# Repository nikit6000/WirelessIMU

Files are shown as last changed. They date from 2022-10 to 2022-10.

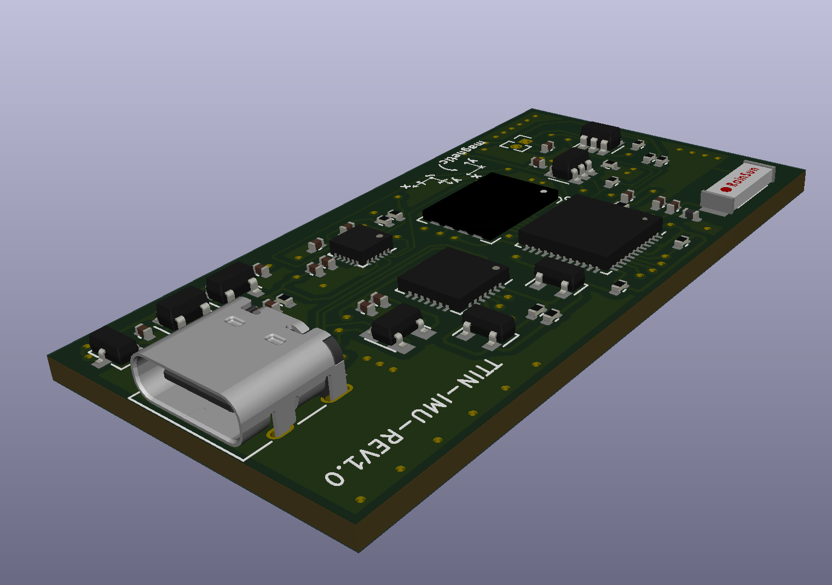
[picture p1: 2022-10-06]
Images/pcb.png

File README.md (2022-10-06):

# WirelessIMU
A board for wireless motion tracking based on `ESP32-PICO-D4` and `MPU9250`. You also can use `ICM-20948` instead of `MPU9250` but you needs to change LDO at `U1` place to 1.8V one

# Capabilities
* Capture RAW Gyroscope, Accelerometer data to embedded storage
* Control over BLE
* Captured data downloading via Wi-Fi

# Applications
* [iOS Application](https://github.com/tokareva13/WirelessIMU-Control)

# Authors
* [Nikita Tarkhov](https://github.com/nikit6000)
* [Tokareva Irina](https://github.com/tokareva13)

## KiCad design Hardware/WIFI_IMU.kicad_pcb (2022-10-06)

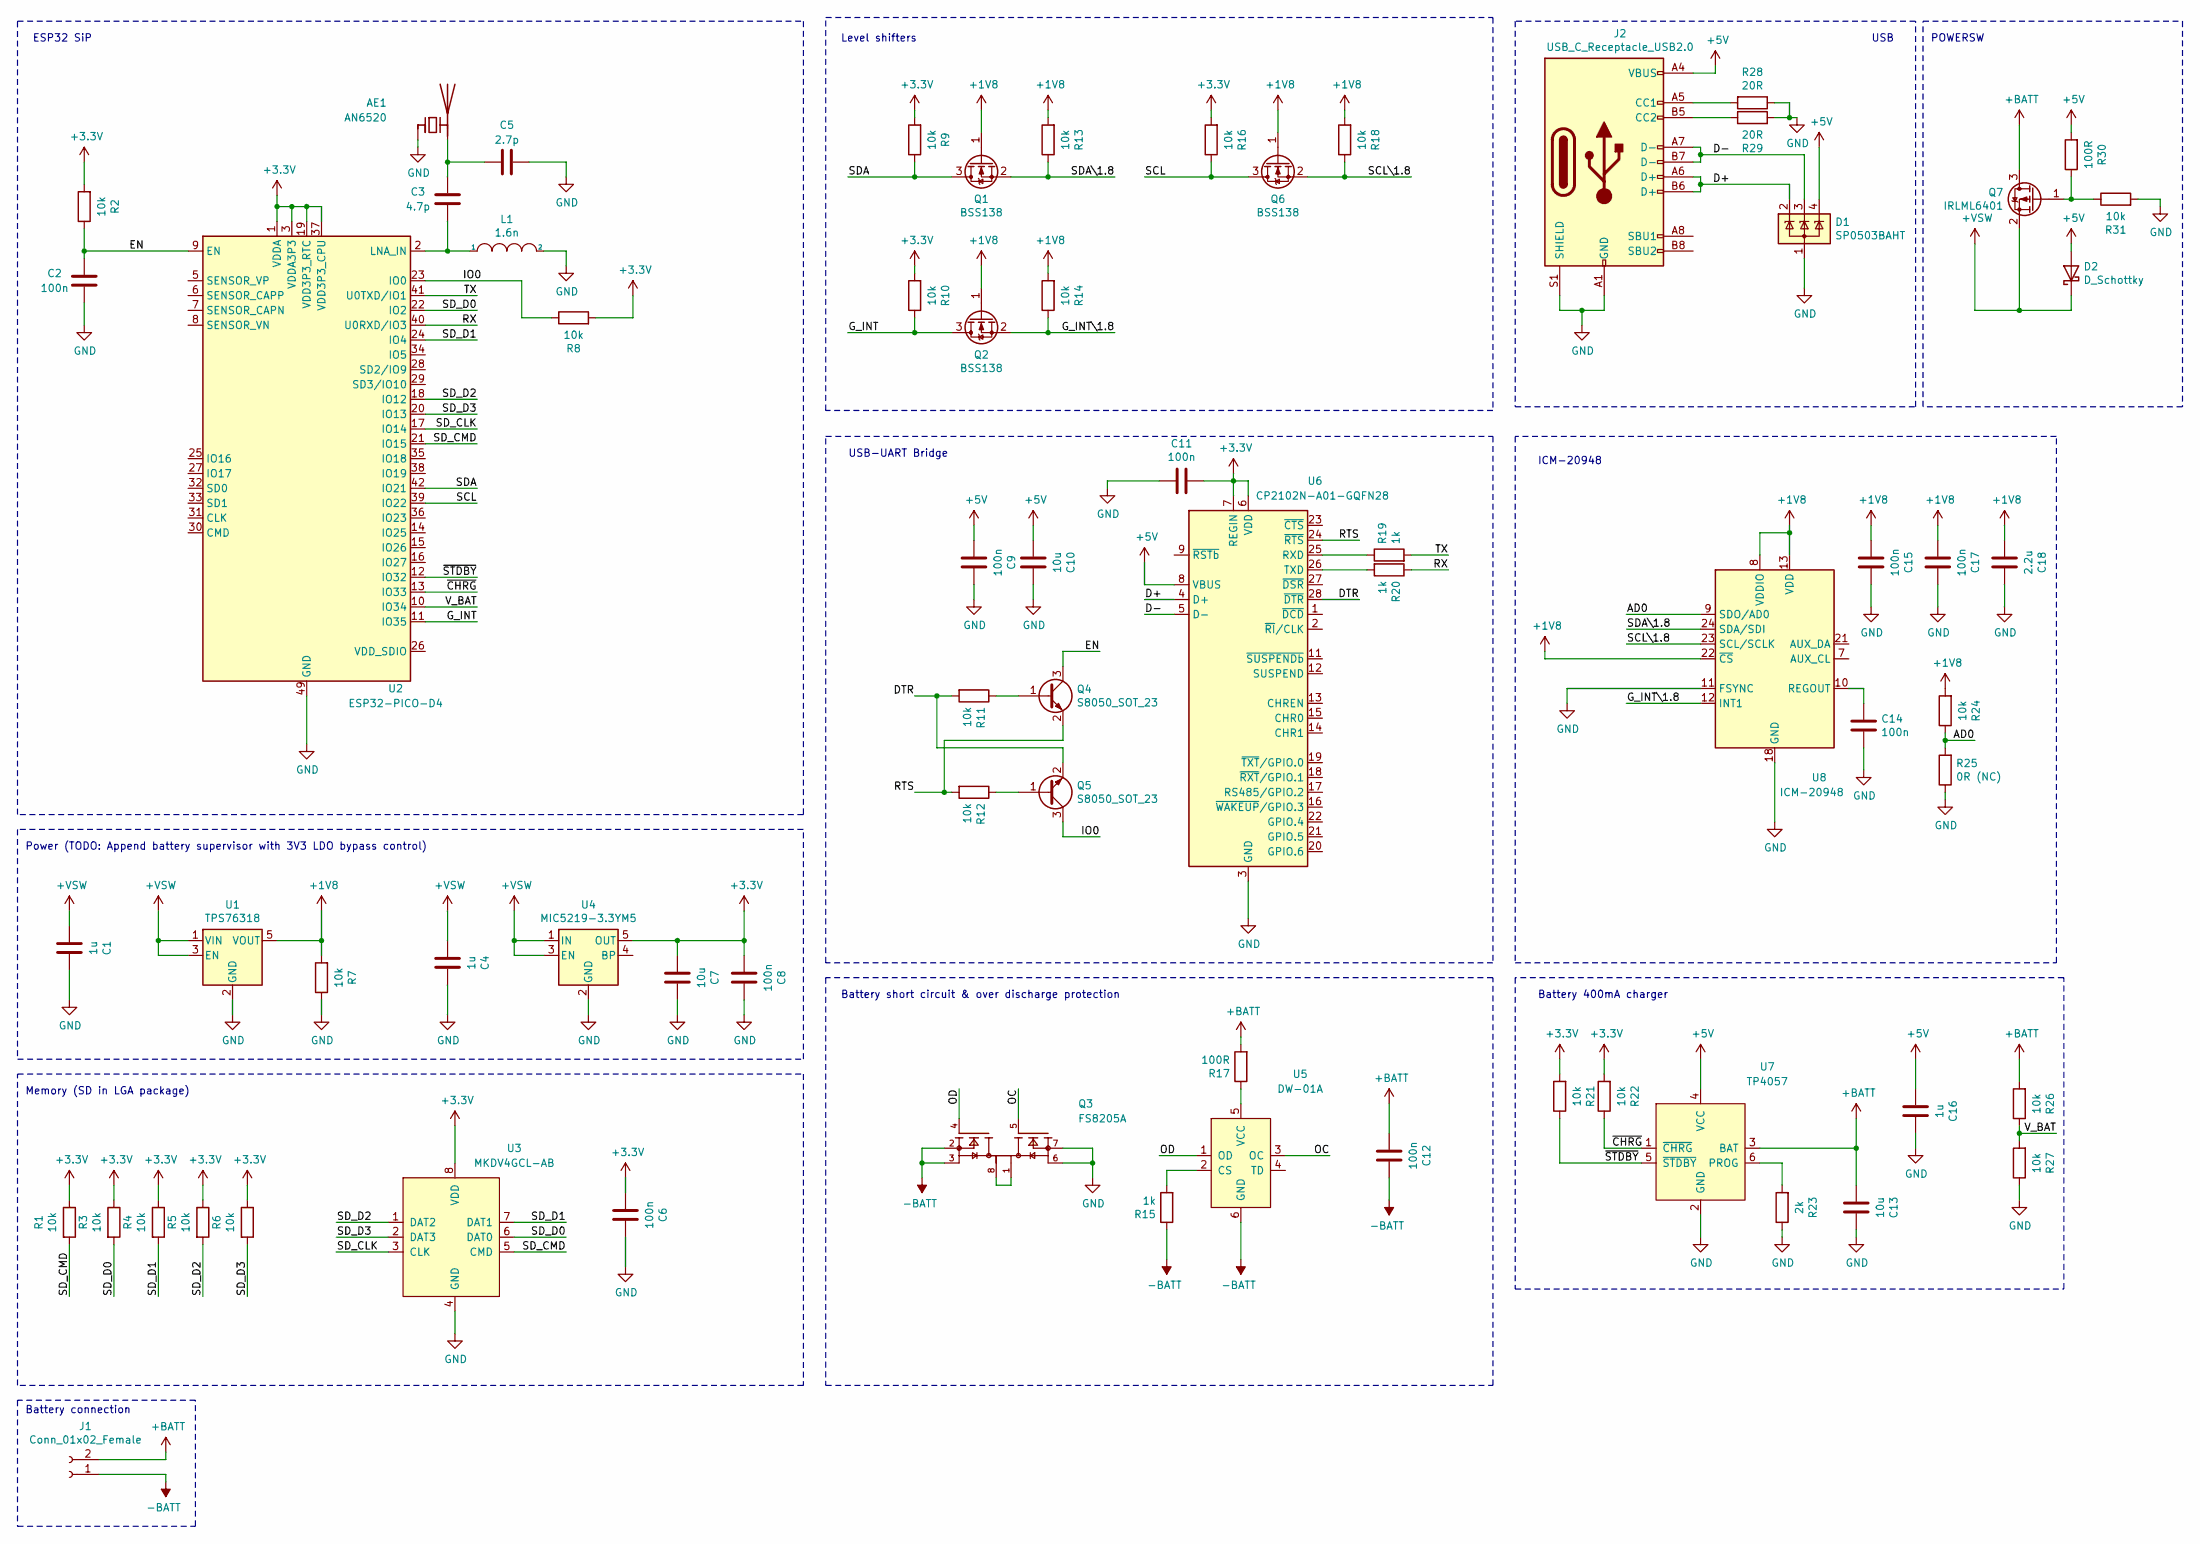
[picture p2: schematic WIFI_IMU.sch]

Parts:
AE1: AN6520; CHIP_ANTENNA_AN6520
C1, C4, C16: 1u; C_0402_1005Metric
C2, C6, C8, C9, C11, C12, C14, C15, C17: 100n; C_0402_1005Metric
C3: 4.7p; C_0402_1005Metric
C5: 2.7p; C_0402_1005Metric
C7, C10, C13: 10u; C_0402_1005Metric
C18: 2.2u; C_0402_1005Metric
D1: SP0503BAHT; SOT-143
D2: D_Schottky; D_SOD-323
J1: Conn_01x02_Female; PinHeader_1x02_P1.27mm_Vertical
J2: USB_C_Receptacle_USB2.0; USB_C_Receptacle_HRO_TYPE-C-31-M-12
L1: 1.6n; L_0402_1005Metric
Q1, Q2, Q6: BSS138; SOT-23
Q3: FS8205A; SOP65P640X120-8N; PARTREV 1.7
Q4, Q5: S8050_SOT_23; SOT-23
Q7: IRLML6401; SOT-23
R1, R2, R3, R4, R5, R6, R7, R8, R9, R10, R11, R12, R13, R14, R16, R18, R21, R22, R24, R26, R27, R31: 10k; R_0402_1005Metric
R15, R19, R20: 1k; R_0402_1005Metric
R17, R30: 100R; R_0402_1005Metric
R23: 2k; R_0402_1005Metric
R25: 0R (NC); R_0402_1005Metric
R28, R29: 20R; R_0402_1005Metric
U1: TPS76318; SOT-23-5
U2: ESP32-PICO-D4; QFN-48-1EP_7x7mm_P0.5mm_EP5.3x5.3mm
U3: MKDV4GCL-AB; LGA-8_8x6mm_P1.27
U4: MIC5219-3.3YM5; SOT-23-5
U5: DW-01A; SOT-23-6
U6: CP2102N-A01-GQFN28; QFN-28-1EP_5x5mm_P0.5mm_EP3.35x3.35mm
U7: TP4057; SOT-23-6
U8: ICM-20948; InvenSense_QFN-24_3x3mm_P0.4mm

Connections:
+1V8: C15.2, C17.2, C18.2, Q1.1 (G), Q2.1 (G), Q6.1 (G), R7.2, R13.2, R14.2, R18.2, R24.2, U1.5 (VOUT), U8.8 (VDDIO), U8.13 (VDD), U8.22 (~CS)
+3V3: C6.2, C7.2, C8.2, C11.1, R1.1, R2.2, R3.1, R4.1, R5.1, R6.1, R8.2, R9.2, R10.2, R16.2, R21.2, R22.2, U2.1 (VDDA), U2.3 (VDDA3P3), U2.4 (VDDA3P3), U2.19 (VDD3P3_RTC), U2.37 (VDD3P3_CPU), U2.43 (VDDA), U2.46 (VDDA), U3.8 (VDD), U4.5 (OUT), U6.6 (VDD), U6.7 (REGIN)
+5V: C9.2, C10.2, C16.2, D1.4 (K), D2.2 (A), J2.A4 (VBUS), J2.A9 (VBUS), J2.B4 (VBUS), J2.B9 (VBUS), R30.2, U6.8 (VBUS), U7.4 (VCC)
+BATT: C12.2, C13.2, J1.2, Q7.3 (D), R17.2, R26.2, U7.3 (BAT)
+VSW: C1.2, C4.2, D2.1 (K), Q7.2 (S), U1.1 (VIN), U1.3 (EN), U4.1 (IN), U4.3 (EN)
-BATT: C12.1, J1.1, Q3.2, Q3.3, R15.1, U5.6 (GND)
/AD0: R24.1, R25.2, U8.9 (SDO/AD0)
/D+: D1.2 (K), J2.A6 (D+), J2.B6 (D+), U6.4 (D+)
/D-: D1.3 (K), J2.A7 (D-), J2.B7 (D-), U6.5 (D-)
/DTR: Q5.2 (E), R11.2, U6.28 (~DTR)
/EN: C2.2, Q4.3 (C), R2.1, U2.9 (EN)
/G_INT: Q2.3 (D), R10.1, U2.11 (IO35)
/G_INT\1.8: Q2.2 (S), R14.1, U8.12 (INT1)
/IO0: Q5.3 (C), R8.1, U2.23 (IO0)
/OC: Q3.5, U5.3 (OC)
/OD: Q3.4, U5.1 (OD)
/RTS: Q4.2 (E), R12.2, U6.24 (~RTS)
/RX: R20.1, U2.40 (U0RXD/IO3)
/SCL: Q6.3 (D), R16.1, U2.39 (IO22)
/SCL\1.8: Q6.2 (S), R18.1, U8.23 (SCL/SCLK)
/SDA: Q1.3 (D), R9.1, U2.42 (IO21)
/SDA\1.8: Q1.2 (S), R13.1, U8.24 (SDA/SDI)
/SD_CLK: U2.17 (IO14), U3.3 (CLK)
/SD_CMD: R1.2, U2.21 (IO15), U3.5 (CMD)
/SD_D0: R3.2, U2.22 (IO2), U3.6 (DAT0)
/SD_D1: R4.2, U2.24 (IO4), U3.7 (DAT1)
/SD_D2: R5.2, U2.18 (IO12), U3.1 (DAT2)
/SD_D3: R6.2, U2.20 (IO13), U3.2 (DAT3)
/TX: R19.2, U2.41 (U0TXD/IO1)
/V_BAT: R26.1, R27.2, U2.10 (IO34)
/~CHRG: R22.1, U2.13 (IO33), U7.1 (~CHRG)
/~STDBY: R21.1, U2.12 (IO32), U7.5 (~STDBY)
GND: AE1.2 (FEED), C1.1, C2.1, C4.1, C5.2, C6.1, C7.1, C8.1, C9.1, C10.1, C11.2, C13.1, C14.1, C15.1, C16.1, C17.1, C18.1, D1.1 (A), J2.A1 (GND), J2.A12 (GND), J2.B1 (GND), J2.B12 (GND), J2.S1 (SHIELD), L1.2, Q3.6, Q3.7, R7.1, R23.1, R25.1, R27.1, R28.1, R29.2, R31.2, U1.2 (GND), U2.49 (GND), U3.4 (GND), U4.2 (GND), U6.3 (GND), U6.29 (GND), U7.2 (GND), U8.11 (FSYNC), U8.18 (GND), U8.20 (GND)
unnamed: AE1.1 (PCB_Trace), C3.2, C5.1
unnamed: C3.1, L1.1, U2.2 (LNA_IN)
unnamed: C14.2, U8.10 (REGOUT)
unnamed: J2.A5 (CC1), R28.2
unnamed: J2.B5 (CC2), R29.1
unnamed: Q3.1, Q3.8
unnamed: Q4.1 (B), R11.1
unnamed: Q5.1 (B), R12.1
unnamed: Q7.1 (G), R30.1, R31.1
unnamed: R15.2, U5.2 (CS)
unnamed: R17.1, U5.5 (VCC)
unnamed: R19.1, U6.25 (RXD)
unnamed: R20.2, U6.26 (TXD)
unnamed: R23.2, U7.6 (PROG)

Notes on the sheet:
ESP32 SiP
USB
USB-UART Bridge
ICM-20948
Level shifters
Power (TODO: Append battery supervisor with 3V3 LDO bypass control)
Memory (SD in LGA package)
Battery short circuit & over discharge protection
Battery 400mA charger
Battery connection
POWERSW

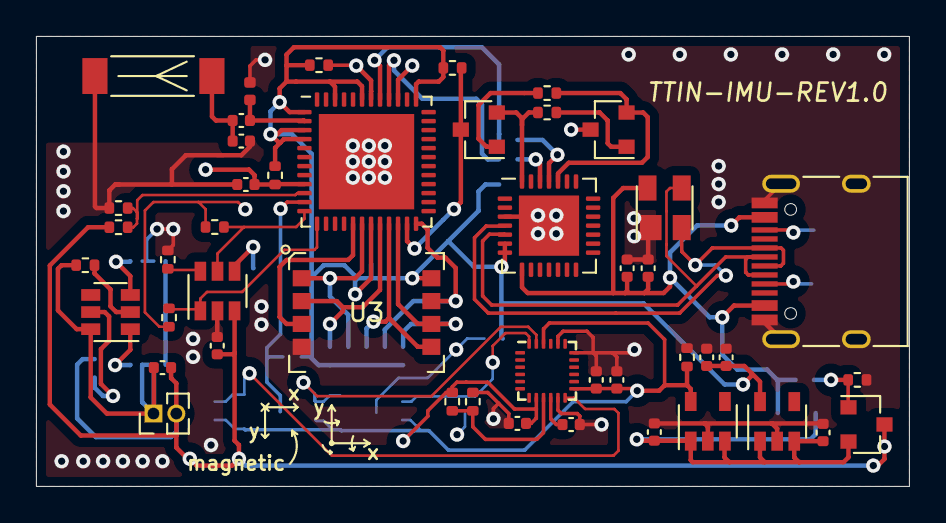
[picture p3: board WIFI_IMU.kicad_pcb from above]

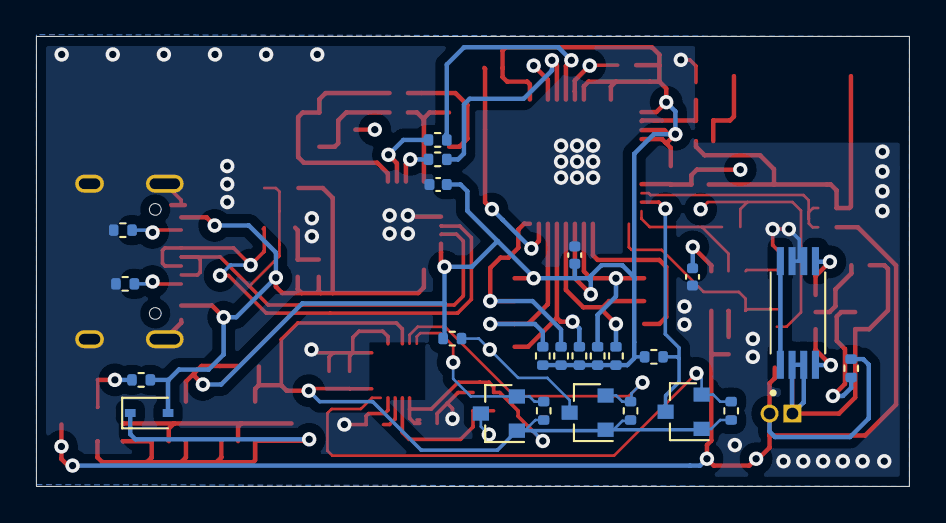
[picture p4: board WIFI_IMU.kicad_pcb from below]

Board: 4 copper layers, 48.5 x 25.0 mm, 70 parts (24 on the bottom side), 47 nets.

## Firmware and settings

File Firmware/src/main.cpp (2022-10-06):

#include <Arduino.h>
#include "FS.h"
#include "SD_MMC.h"
#include <math.h>
#include <SparkFunMPU9250-DMP.h>
#include "Services/SyncService.h"

void setupServices(void);

static const char* MAIN_TAG = "MAIN";

void setup() 
{
  esp_log_level_set("*", ESP_LOG_INFO); 
  Serial.begin(115200);
  setupServices();
}

void setupServices(void) {
  if(SyncService::shared().configure()) {
    ESP_LOGI(MAIN_TAG, "Initialization was success");
  } else {
    ESP_LOGI(MAIN_TAG, "Initialization was unsuccess");
  }
}

void loop() 
{
  SyncService::shared().loop();
}

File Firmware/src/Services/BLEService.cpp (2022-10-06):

#include "BLEService.h"
#include <Arduino.h>
#include <esp_log.h>
#include <rom/crc.h>

#define SERVICE_UUID           "6E400001-B5A3-F393-E0A9-E50E24DCCA9E" // UART service UUID
#define CHARACTERISTIC_UUID_RX "6E400002-B5A3-F393-E0A9-E50E24DCCA9E"
#define CHARACTERISTIC_UUID_TX "6E400003-B5A3-F393-E0A9-E50E24DCCA9E" 

static const char* BLE_TAG = "BLEDev";

BLEDeviceService::BLEDeviceService() {
    mutex = xSemaphoreCreateMutex();
    pServer = nullptr;
    pTxCharacteristic = nullptr;
    delegate = nullptr;
    connecteDeviceId = 0;
    setState(State::uninitialized);
}

bool BLEDeviceService::configure() {
    BLEDevice::init(BLE_SERVICE_DEVICE_NAME);
    
    // Create the BLE Server
    pServer = BLEDevice::createServer();
    pServer->setCallbacks(this);

    // Create the BLE Service
    BLEService *pService = pServer->createService(SERVICE_UUID);

    // Create a BLE Characteristic
    pTxCharacteristic = pService->createCharacteristic(
                                            CHARACTERISTIC_UUID_TX,
                                            BLECharacteristic::PROPERTY_NOTIFY
                                        );
                      
    pTxCharacteristic->addDescriptor(new BLE2902());

    BLECharacteristic * pRxCharacteristic = pService->createCharacteristic(
                                            CHARACTERISTIC_UUID_RX,
                                            BLECharacteristic::PROPERTY_WRITE
                                        );

    pRxCharacteristic->setCallbacks(this);

    // Start the service
    pService->start();

    // Start advertising
    pServer->getAdvertising()->addServiceUUID(SERVICE_UUID);
    pServer->getAdvertising()->start();
    ESP_LOGI(BLE_TAG, "BLE Server configured");
    setState(State::idle);
    return true;
}

void BLEDeviceService::setState(State newState) {
    const char* stateString;
    switch (newState)
    {
    case State::idle:
        stateString = "idle";
        break;
    case State::connected:
        stateString = "connected";
        break;
    case State::uninitialized:
        stateString = "uninitialized";
        break;
    default:
        stateString = "unknown";
        break;
    }
    //ESP_LOGI(BLE_TAG, "BLE current state: %s", stateString);
    Serial.print("BLE current state: ");
    Serial.println(stateString);
    state = newState;
}

void BLEDeviceService::writeResponseWithRandomNum(AnswerType type, RequestType requestType) {
    uint16_t randomNumber = esp_random() & 0xFFFF;
    writeResponse(type, requestType, (uint8_t*)&randomNumber, sizeof(uint16_t));
}

void BLEDeviceService::writeResponse(AnswerType type, RequestType requestType, uint8_t* data, size_t dataLen) {
    size_t headerSize = sizeof(AnswerHeader);
    size_t packetSize = headerSize + dataLen + 4;
    uint8_t* packet = new uint8_t[packetSize];
    uint8_t* offsettedPacket = packet;

    if (!packet) {
        return;
    }

    AnswerHeader header;
    header.type = type;
    header.requestType = requestType;
    header.sequeceNum = sequenceNum;
    header.size = dataLen;

    memcpy(offsettedPacket, &header, headerSize);

    offsettedPacket += headerSize;

    if (data && dataLen > 0) {
        memcpy(offsettedPacket, data, dataLen);
    }

    offsettedPacket += dataLen;

    uint32_t crc = crc32_le(0, packet, packetSize - 4);

    memcpy(offsettedPacket, &crc, sizeof(uint32_t));

    sequenceNum += 1;
    
    pTxCharacteristic->setValue(packet, packetSize);
    pTxCharacteristic->notify();
    delete [] packet;
}

void BLEDeviceService::setDelegate(BLEDeviceServiceDelegate* observer) {
    this->delegate = observer;
}

// BLECharacteristicCallbacks
void BLEDeviceService::onRead(BLECharacteristic* pCharacteristic) {

}

void BLEDeviceService::onWrite(BLECharacteristic* pCharacteristic) {
    std::string value = pCharacteristic->getValue();
    uint8_t* data = (uint8_t*)value.data();
    size_t dataLen = value.length();
    size_t headerLen = sizeof(RequestHeader);
    uint32_t crc;

    if (dataLen < headerLen + 4) {
        writeResponseWithRandomNum(AnswerType::error, RequestType::requestError);
        return;
    }

    RequestHeader* header = (RequestHeader*)data;
    uint8_t* payload = data + headerLen;

    dataLen -= headerLen;

    if (dataLen < header->size) {
        writeResponseWithRandomNum(AnswerType::error, header->type);
        return;
    }

    dataLen -= header->size;
    uint8_t* crcData = payload + header->size;

    if (dataLen < 4) {
        writeResponseWithRandomNum(AnswerType::error, header->type);
        return;
    }

    uint32_t* packetCRC = (uint32_t*)crcData;

    crc = crc32_le(0, data, value.length() - 4);

    if (*packetCRC != crc) {
        Serial.printf("Wrong CRC %X != %X\n", *packetCRC, crc);
        writeResponseWithRandomNum(AnswerType::error, header->type);
        return;
    }

    if (delegate == nullptr) {
        writeResponseWithRandomNum(AnswerType::error, header->type);
        return;
    }

    switch (header->type)
    {
    case RequestType::beginSampling:
        {
            delegate->bluetoothDeviceServiceStartSampling(this);
            break;
        }
    case RequestType::endSampling:
        {
            delegate->bluetoothDeviceServiceStopSampling(this);
            break;
        }
    case RequestType::beginCalibration:
        {
            delegate->bluetoothDeviceServiceBeginCalibration(this);
            break;
        }
    case RequestType::requetFileTransfer: 
        {
            delegate->bluetoothDeviceServiceRequestDataTransfer(this);
            break;
        }
    case RequestType::setSamplingFreq: 
        {
            uint16_t* freq = (uint16_t*)payload;
            delegate->bluetoothDeviceServiceSetSamplingRate(this, *freq);
            break;
        }
    default:
        {
            writeResponseWithRandomNum(AnswerType::error, header->type);
            break;
        }
    }
}

void BLEDeviceService::onNotify(BLECharacteristic* pCharacteristic) {

}

// BLEServerCallbacks
void BLEDeviceService::onConnect(BLEServer* pServer, esp_ble_gatts_cb_param_t* param)  {
    //ESP_LOGI(BLE_TAG, "BLE device connected");
    Serial.print("BLE device connected: ");
    Serial.println(param->connect.conn_id);

    if (state != State::idle) {
        pServer->disconnect(param->connect.conn_id);
        return;
    }
    sequenceNum = 0;
    connecteDeviceId = param->connect.conn_id;
    setState(State::connected);
}

void BLEDeviceService::onDisconnect(BLEServer* pServer) {
    Serial.print("BLE device disconnected ");
    if (pServer->getConnId() != connecteDeviceId) {
        Serial.println(pServer->getConnId());
        return;
    }
    Serial.println(connecteDeviceId);
    connecteDeviceId = 0;
    setState(State::idle);
    pServer->startAdvertising();
}

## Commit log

2022-10-06 Initail commit
    [WIFI_IMU.kicad_pcb, WIFI_IMU.sch]
2022-10-06 Add PCB image
